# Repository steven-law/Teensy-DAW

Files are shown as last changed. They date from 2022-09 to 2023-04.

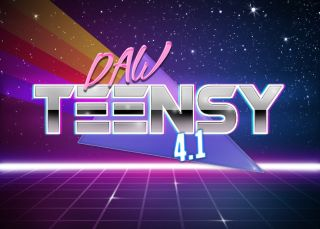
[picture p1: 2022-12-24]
sdcontent/StartUpPic.bmp

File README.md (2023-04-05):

#
Please join this Discord channel for best feature updates, informations and other chats.  
The most updated files are still here, tho.  
https://discord.gg/N78atDz9bC
please Note:
At the moment the latest updates are in the "Steven-Law" branch

Teensy-DAW
 clipbased Touch DAW for Teensy

.) 8 tracks  
.) 8 individual clips per track  
.) 16 steps per clip  
.) +4 different Sequencer Modes ("Step", "Grid", "Drop", "Rand")  
.) sequence external Midi gear (Midichannel 1 - 16) or (if "Midichannel" is above 16)  
.) 8+ internal plugins , several sampleplayers and synthesis  
.) each plugin can save 8 presets to sd card  
.) more plugins can be easily added. Tutorial inside  
.) send 16 midi cc´s per track when Midichannel is set to 1-16  
.) whole project or each page can be saved/loaded indiviually to sd card  
.) Songmode /Arrangement Mode  
.) navigation via touchscreen, buttons or encoders  
.) control 4 paramters in a row immediatly with the knobs or 4 pots from your controller/keyboard  
.) automatic pot assign for different pages  
.) connect a keyboard like the keyste37 (or any other KB with 4 Knobs) for best integration  
.) connect up to 5 usbmidi-synthesizer over a usb-hub/ or standard TRS Type A = Korg/Roland/..  
.) Record or play live via USB Keyboard  
.) Record external Audio to RAW files   
.) scales can be highlighted in sequencer view  
.) use a Launchpad mini (MK1) to launch Clips directly  
.) 

Implemented plugins:  
1) Chord-Plugin  
2) SdCard-WAV Drumplayer, very rudimentary for now   
3) 1OSC Voice  (with Tutorial)  
4) FlashMem Drumplayer  
5) SD melodic sampler  
6) SD *.raw melodic sampler  
7) drum synth  
8) 1OSC with moog ladder filter   

Songmode:  
.) the individual clips can be arranged in songmode  
.) songs can be up to 255 bars long  
.) set individual note offsets (transpose) per beat  
.) set individual Plugin Preset per beat  
.) set individual Volumes per beat  
.) loop function to loop desired bars  
.)   
  
Drumtrack:  
.) sequence one of the internal drum plugins   
.) send up to 12 individual Midi notes to ext gear like Drummachines  
.) sent notes can be easily applied  
.)   
  
Melodic Tracks 2-8:  
.) sequence one of the internal melodic plugins   
.) send Midinotes to ext gear like Monophonic Synthesizers  
.)   
  
Mixer:  
.) mix internal plugins / MIDI Velocity  
.) solo and mute function  
.) 3 fx slots with individual sends per track  
.)  
  
Audio Recorder:  
.) Record Line Level to RAW  
.) choose one of 128 RAW Files  
.) apply Gain to the signal  
.) Pre-Listen /Monitor your signal  
.) record by hitting Rec, press again to stop recoording  
.)

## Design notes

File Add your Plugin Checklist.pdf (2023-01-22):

# Add your Plugin Checklist

.) Think yourself of a cool Plugin

.) Implement the modules into the Teensy-Touch-DAW Audiochain.

.) Export the new AudioChain and replace it with the existing one

.) Add the 6 Gainstages to the Array of pointers

.) Place your control variables in variables.ino.

.) Add these 7 functions to your new plugin *.ino file

.) “void Plugin_3_Settings()”

.) “void Plugin3_Control()”

.) “void Plugin3_Page1_Dynamic()”

.) “void Plugin3_Page_Static(byte Pagenumber)”

.) “void Plugin3_Change()”

.) “void savePlugin3()”

.) “void loadPlugin3()”

.) Think yourself of a cool Plugin and what controls you want to have

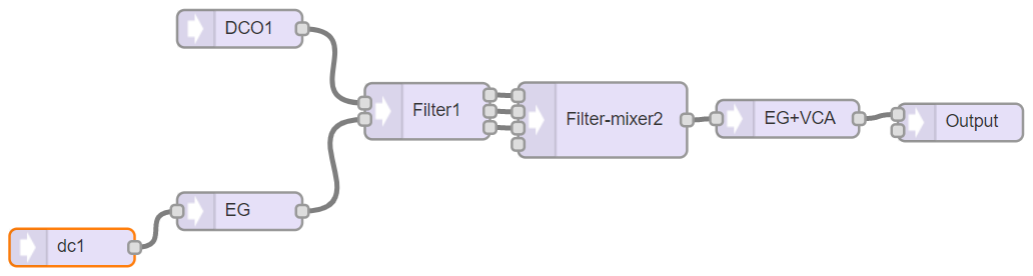
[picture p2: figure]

.) Implement the modules into the Teensy-Touch-DAW Audiochain.
Copy the existing AudioChain-Code into Newdigate´s AudioTool. Paste your Plugin inside. Don't forget the 2 Gain stages for MAX Volume and Volume/bar
as well as the 4 Gain modules for the FX´s

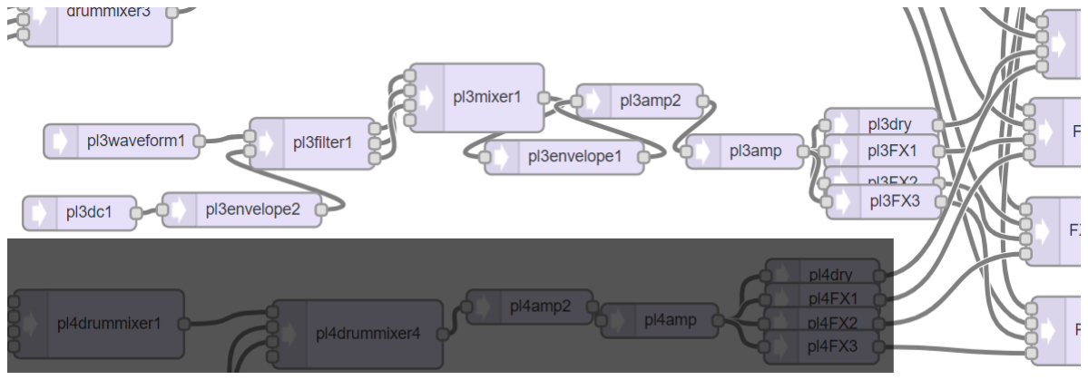
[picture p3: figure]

.) Export the new AudioChain and replace it with the existing one

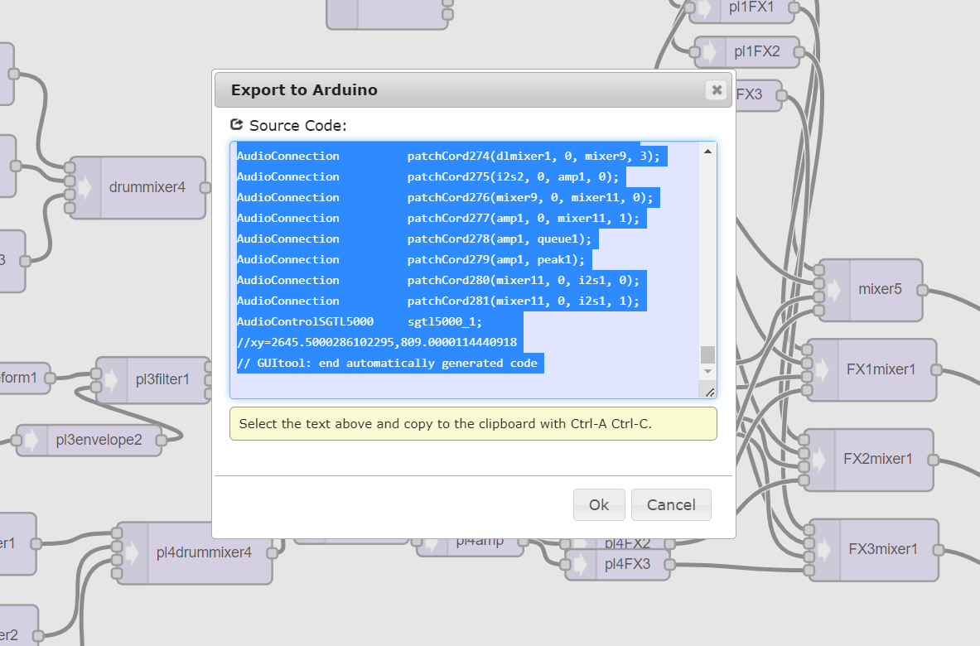
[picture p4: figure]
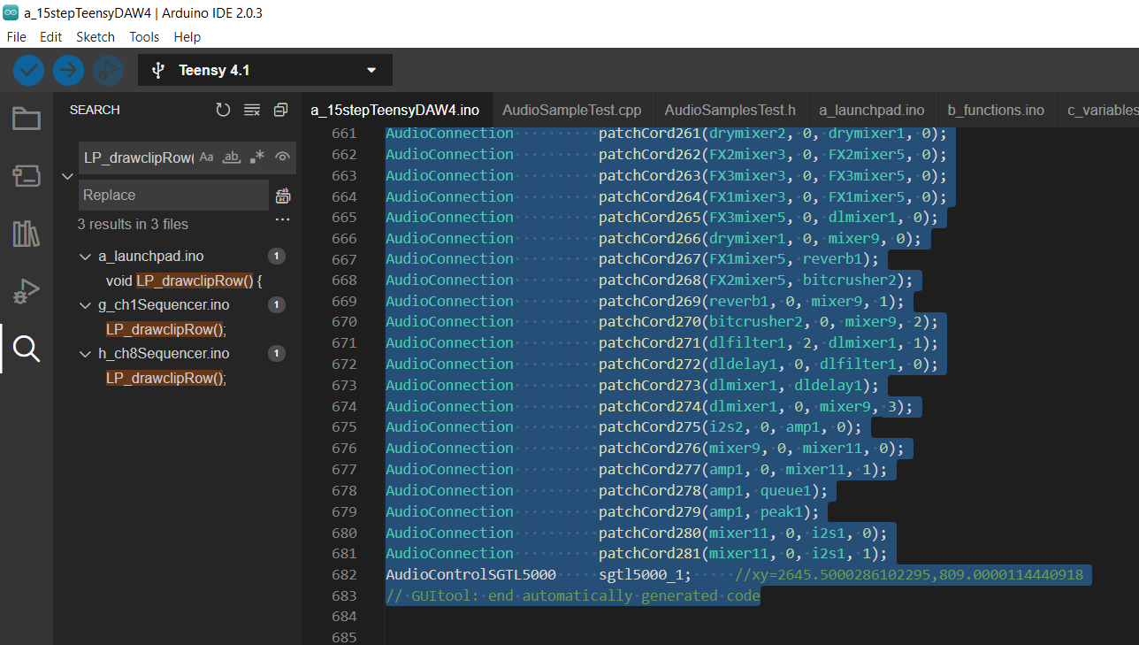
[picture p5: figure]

=>

.) *Add the 6 Gainstages to the Array of pointers
* If we have reached the max amount of Plugins, i´ve made a template for, we have to add new Gain stages. But there is most likely also other stuff to do

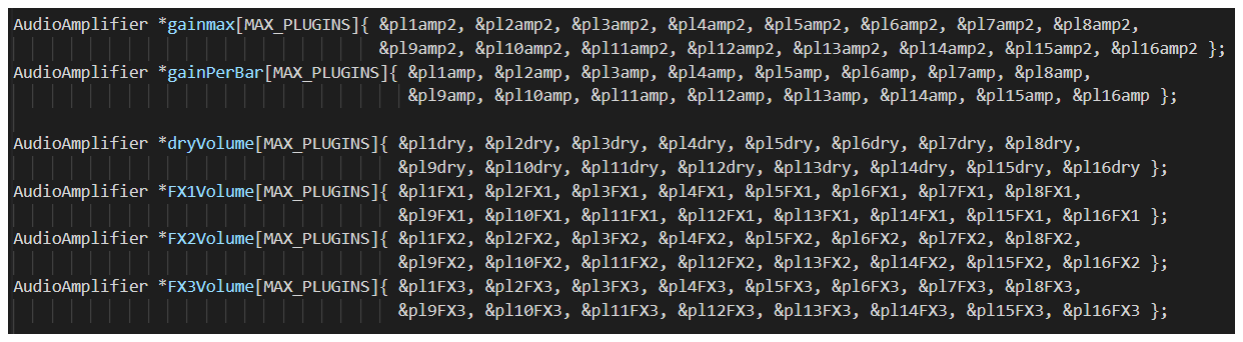
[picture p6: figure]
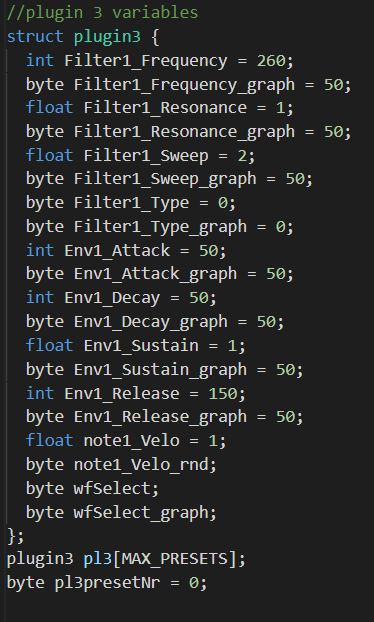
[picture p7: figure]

.) Place your control variables in variables.ino.
Use a “struct” for saving presets. For each control you need 2 variables:

byte/float/int “module_function”; // your desired range
byte | “module_function”_graph; // range: 0-127

Also set your Plugin name into the PluginName[] Array!!

.) Add these 7 functions to your new plugin *.ino file void Plugin_3_Settings()
void Plugin3_Control()
void Plugin3_Page1_Dynamic()
void Plugin3_Page_Static(byte Pagenumber) void Plugin3_Change()

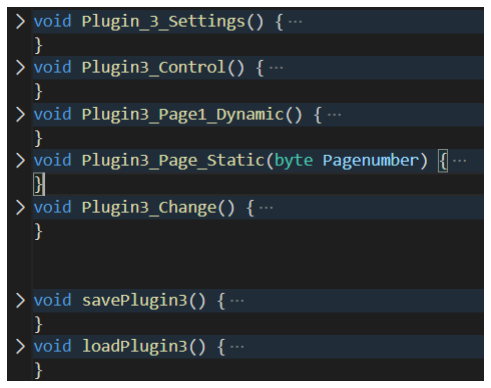
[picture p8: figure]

void savePlugin3()
void loadPlugin3()

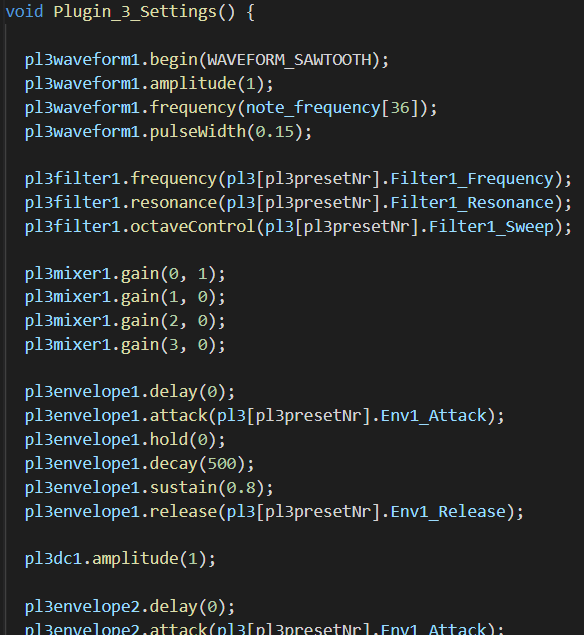
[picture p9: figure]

.) “void Plugin_3_Settings()”
This function is used to set all functions from the used Modules to a desired start value.
Give all functions a desired value. Some functions may not be used, but then they are set to the correct value.

Copy this function in “functions.ino to:
void setup {}

.) “void Plugin3_Control()”
This function is used to map the _graph value to the desired “function”-range.
For every function you want to control add your assignment here. Each switch-case stands for one of the four rows. This is the most code you have to write. In the end your “PluginX_Control” function will be about 100 lines long, if you use this method:

if (pl3[pl3presetNr].***_graph != Potentiometer[x]) {
pl3[pl3presetNr].***_graph = Potentiometer[x];
pl3[pl3presetNr].*** = map(pl3[pl3presetNr].***_graph, 0, 127, min, max); module.function(pl3[pl3presetNr].***);
drawPot(CTRL_COL_x, CTRL_ROW_x, pl3[pl3presetNr].***_graph, pl3[pl3presetNr].***, "***", trackColor[desired_track]);
}
where *** is the desired function.

Copy this function in “functions.ino to: void Plugin_View_Dynamic() {}

.) “void Plugin3_Page1_Dynamic()”
This function is used to assign the Encoder Movement to the desired _graph value. Here we add the Encoder value to the last stored “plX[desired_track].***_graph” value and give it to “Potentiometer[x]”. Do this for every control you have added above.

Potentiometer[x] = pl3[pl3presetNr].***_graph;
if (enc_moved[x]) {
Potentiometer[x] = constrain((pl3[pl3presetNr].***_graph + encoded[0]), 0, 127); }
where *** is the desired function.

Copy this function in “functions.ino to:
void Plugin_View_Dynamic() {}

.) “void Plugin3_Page_Static(byte Pagenumber)”
This function is used to show your controls once after you switch presets.
Copy the drawPot() functions from “PluginX_Control” into this function. Whenever you call your Plugins Page, these are the things that will show up. Add “clearworkspace()”, your “PluginX_Change()” and the rectangle for the Preset Number functions. This function is only called once.Don't put any interactive stuff inside.

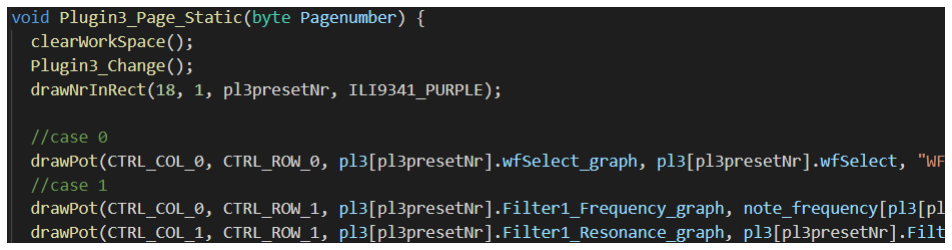
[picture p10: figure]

Copy this function in “functions.ino to: void Plugin_View_Static() {}

.) “void Plugin3_Change()”
This function is used for preset changes.
Copy the | module.function(pl3[pl3presetNr].***); | module´s functions into this page.

Copy this function in “functions.ino to:
void beatComponents {}
and your
void Plugin3_Page_Static(byte Pagenumber)

.) “void savePlugin3()”
This function is used to save your Presets.
Copy one of the existing save_Plugin() functions into your file and change the _graph variable to yours.

Copy this function in “songmode.ino to:
void savebutton {}
and your
void Plugin3_Page_Dynamic()

.) “void loadPlugin3()”
This function is used to load your Presets.
Copy one of the existing load_Plugin() functions into your file and change the _graph variable to yours.

Copy this function in “songmode.ino to:
void loadbutton {}
and your
void Plugin3_Page_Dynamic()

.) NoteOn/NoteOff´s
Add your NoteOn/NoteOff´s into the “void PluginPlay()” function.
From here your Plugin will be played via the sequencer, a MIDI Keyboard or the Launchpad.

Done!!!

Useful Lines:
selectFilterType(pluginchannel, mixerchannel) //if you want a selectable filtertype add your filtermixer inside
drawPot(xPos, yPos, fvalue, dvalue, dname, color); | //fvalue = ***_graph; dvalue = ***
drawNrInRect(xPos, yPos, dvalue, color); | // dvalue = ***
clearWorkSpace();

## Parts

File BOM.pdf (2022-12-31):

| | BOM
1 | 1 | Teensy 4.1 | https://www.pjrc.com/store/teensy41.html
2 | 1 | Teensy Audio Shield Rev D | https://www.pjrc.com/store/teensy3_audio.html
3 | 1 | TFT ILI9341 2.8" | https://www.amazon.de/gp/product/B07YTWRZGR/ref=ppx_yo_dt_b_asin_title_o00_s00?ie=UTF8&psc=1
4 | 4 | Encoder with switch | any will do
5 | 16 | 6x6mm tactile switch | https://www.mouser.at/ProductDetail/E-Switch/TL1105SPF160Q?qs=01kh3H%252BlXiincFtVDb4Rog%3D%3D
6 | 16 | 1RWHT caps | https://www.mouser.at/ProductDetail/612-1RWHT
7 | 4 | SJ1-3533NG stereo jack | https://www.mouser.at/ProductDetail/490-SJ1-3533NG
8 | 2 | 929870-01-14-RA flat header | https://www.mouser.at/ProductDetail/517-929870-01-14-RA
9 | 17 | 1N4148 Diodes | https://www.mouser.at/ProductDetail/onsemi-Fairchild/1N4148?qs=i4Fj9T%2FoRm8RMUhj5DeFQg%3D%3D
10 | 2 | 47R Resistor | any will do
11 | 1 | 100R Resistor | any will do

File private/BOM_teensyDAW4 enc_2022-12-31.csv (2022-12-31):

ID | Name | Designator | Footprint | Quantity | Manufacturer Part | Manufacturer | Supplier | Supplier Part | Price
1 | 1N4148 | D1,D2,D3,D4,D5,D6,D7,D8,D9,D10,D11,D12,D13,D14,D15,D16,D17 | DO-35_BD2.0-L4.2-P8.20-D0.5-RD | 17 | 1N4148 | STMicroelectronics | LCSC | C13769
2 | SJ1-3533NG | J1,J2,J3,J4 | JACK_3.5MM-SJ1-3533NG | 4 | SJ1-3533NG | null | LCSC | C9900019346
3 | 220R | R1,R2 | R_AXIAL-0.3 | 2
4 | 100R | R5 | R_AXIAL-0.6 | 1
5 | TC-1102-C-P-B | SW1,SW2,SW3,SW4,SW5,SW6,SW7,SW8,SW9,SW10,SW11,SW12,SW13,SW14,SW15,SW16 | KEY-TH_4P-L6.0-W6.0-P4.50-LS6.50 | 16 | TC-1102-C-P-B | XKB Connectivity(中国星坤) | LCSC | C2885143 | 0.005
6 | TEENSY_41_AUDIO_SHIELD_ONLY COPY | T1 | TEENSY_4_1_AUDIO_SHIELD_ONLY COPY | 1 | PJRC
7 | MYTFT_TOUCH_SPI_2.8IN-ILI9341 COPY | U1 | MYTFT_TOUCHSPI_2.8IN-ILI9341 | 1
8 | Teensy_4.1 | U2 | TEENSY4.1UNTEN | 1 | Teensy_4.1 | PJRC | www.pjrc.com | Teensy_4.1
9 | ENCODER_SW1-PEC12 | SW17,SW18,SW19,SW20 | PEC12_INCREMENTAL_ENCODER | 4

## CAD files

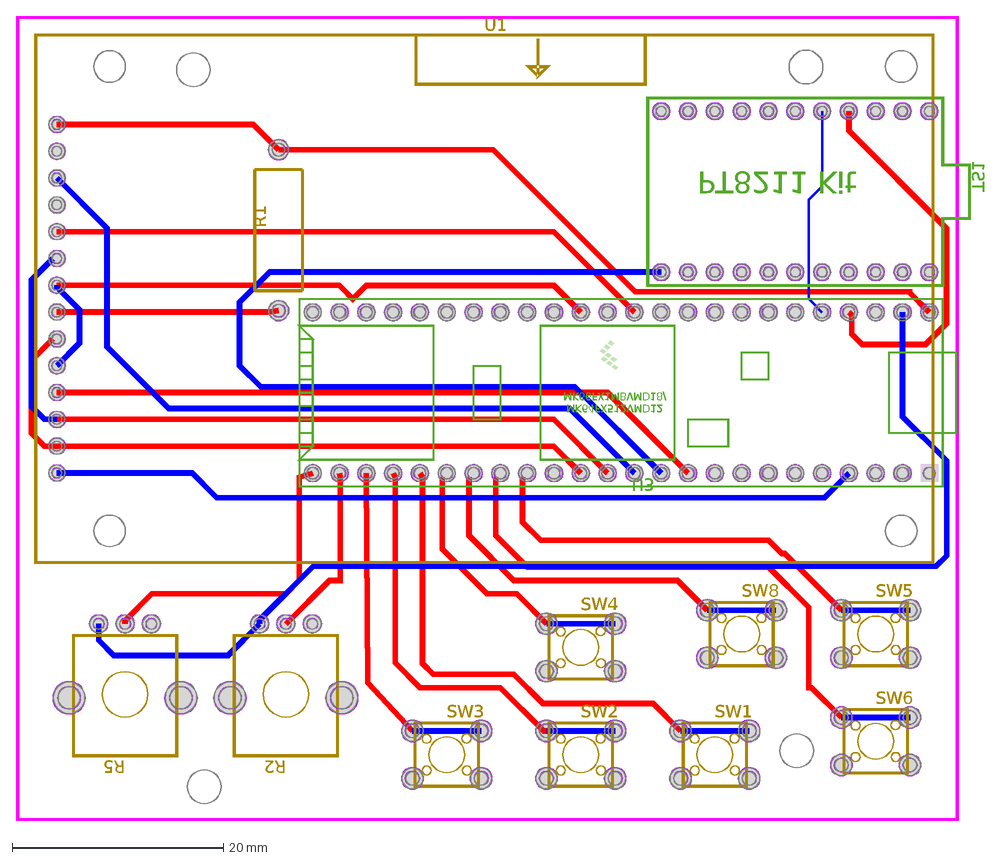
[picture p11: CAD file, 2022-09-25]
hardware/PCB_teensyDAW_2022-09-21.dxf
TS1
PT8211 Kit
U3
MK66FX1MBVMD18/
MK64FX512VMD12
SW1
SW2
SW3
SW4
SW5
SW6
SW8
R1
R5
U1
R2

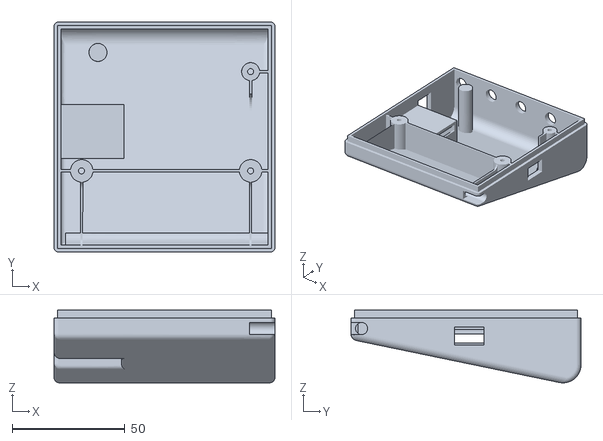
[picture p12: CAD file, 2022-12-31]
Housing/touchdaw41Enc.stl
98.0 x 102.0 x 32.3

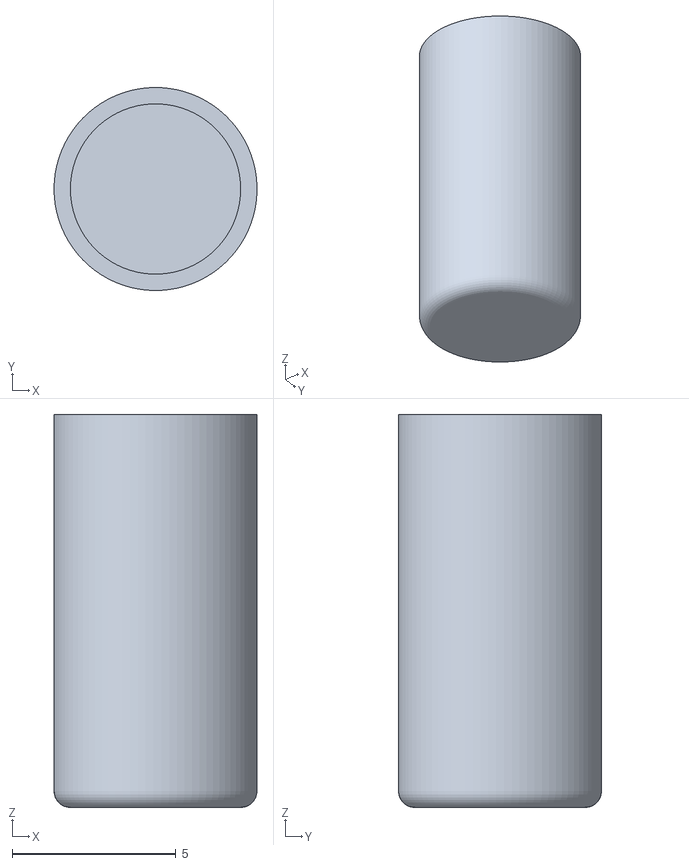
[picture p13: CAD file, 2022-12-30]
Housing/buttonextension12.stl
6.20 x 6.20 x 12.0

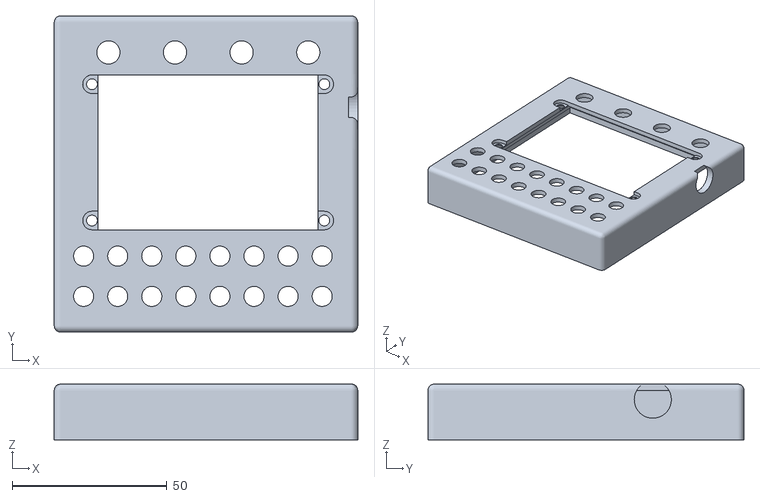
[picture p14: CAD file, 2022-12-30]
Housing/touchdaw41obenEnc.stl
98.0 x 102.0 x 18.0

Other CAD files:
hardware/PCB_teensyDAW_2022-09-21-2.dxf
hardware/PCB_teensyDAW_2022-09-21-2.dwg

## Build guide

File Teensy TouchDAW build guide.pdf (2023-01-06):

# Build Guide:

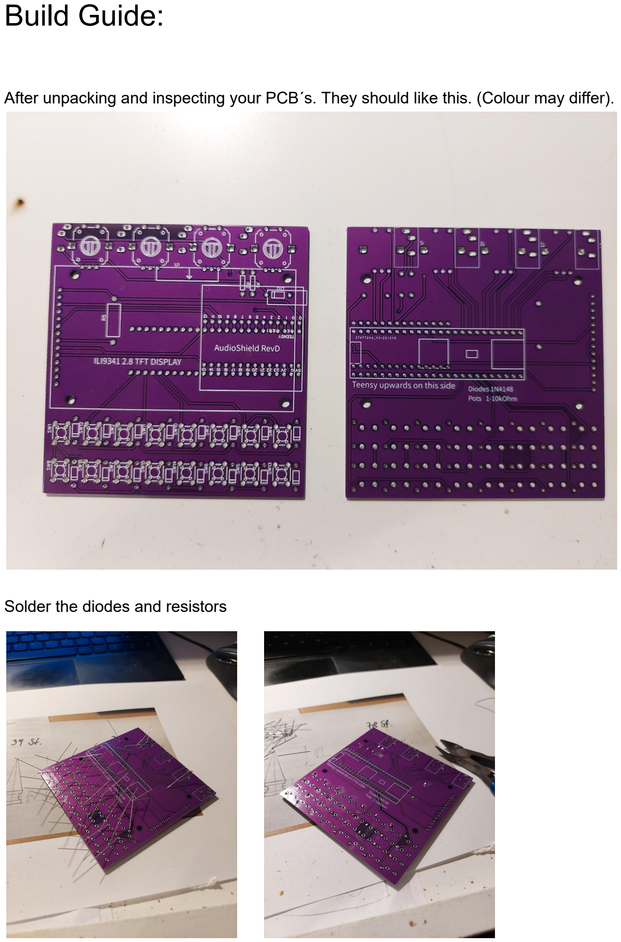
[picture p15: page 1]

After unpacking and inspecting your PCB´s. They should like this. (Colour may differ).

Solder the diodes and resistors

Solder the Buttons

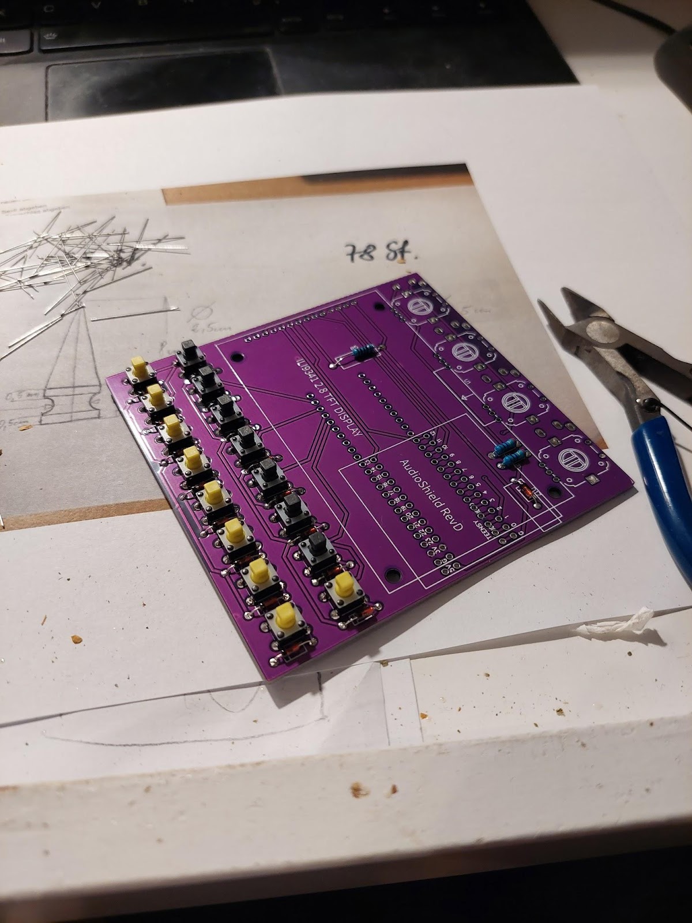
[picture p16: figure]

Solder the headers
- long headers on the backside
- short headers on the top side
- header for display on the top side

Solder the Encoders

Solder Teensy 4.1 headers
- pay attention to the orientation

Sodler Audio shield Headers
- pay attention to the pin length

tbc

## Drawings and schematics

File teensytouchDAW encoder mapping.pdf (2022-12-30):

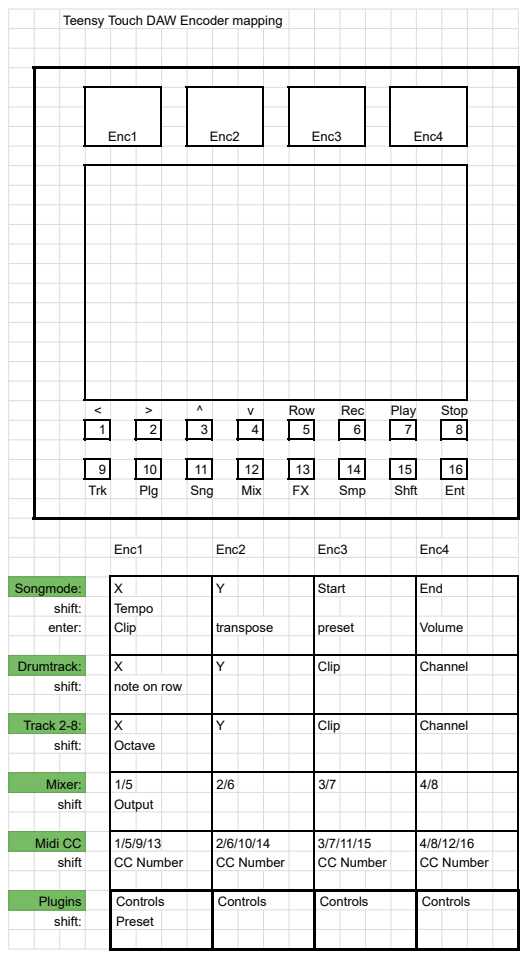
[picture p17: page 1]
Enc1; Enc2; Enc3; Enc4; Row; Rec; Stop; Trk; Plg; Sng; Mix; Smp; Shft; Ent; Songmode:; Start; End; shift:; Tempo; enter:; transpose; preset; Volume; Drumtrack:; Channel; note on row; Track 2-8:; Octave; Mixer:; shift; Output; Midi CC; CC Number; Plugins; Controls; Preset; Play

Teensy Touch DAW Encoder mapping

Clip

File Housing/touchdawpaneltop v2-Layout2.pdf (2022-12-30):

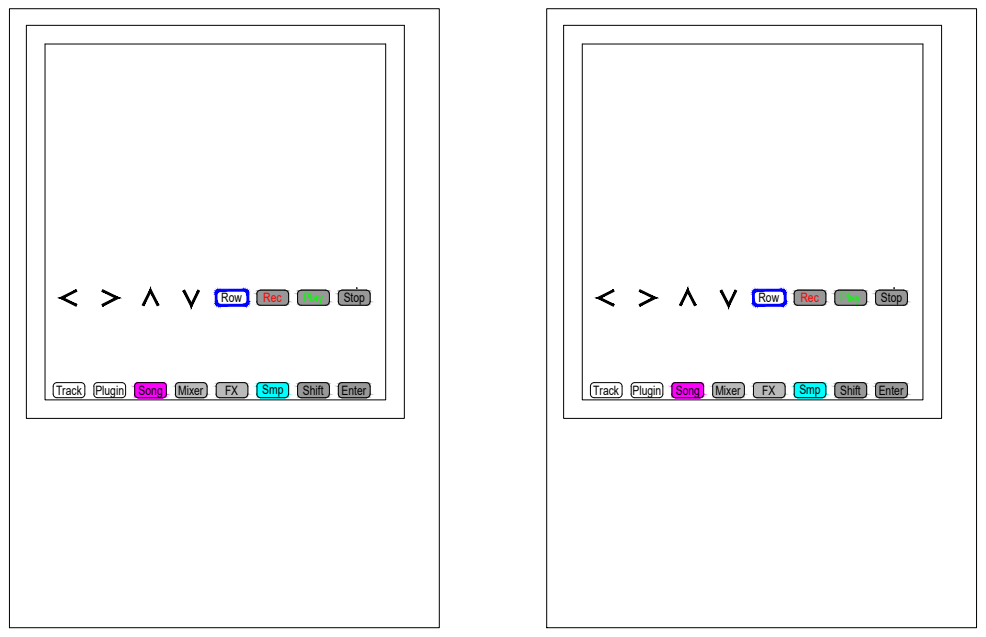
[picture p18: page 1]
Track; Plugin; Song; Mixer; Shift; Enter Rec; Play; Stop FX; Smp Row Track; Smp Row

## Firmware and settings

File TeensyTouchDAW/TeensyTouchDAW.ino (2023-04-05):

bool debugTime = false;
extern unsigned long _heap_start;
extern unsigned long _heap_end;
extern char *__brkval;
/*Contributing Manual:

Many Thanks to Tristan Rowley, without his immense efforts and time to explain things to me, 
this project would have never reached this amount of functions and still have a more or less readable code. 
For more Informations on him, please take a look at www.github.com/doctea and www.doctea.co.uk!!  
Very Interesting stuff to find and try out!!!

Hello. Here i will show you how to implement new stuff easily.

There are some things left to be made at this point, but feel free to add your features.

toDo´s:
    • add polyphony
    • if in the stepsequencer of a track, i would like to hear the selected clip. when in songmode, only play the arrangment 



1. 15stepTeensyDAW3.ino :

This is the main sketch. It is easier to look at it in chapters: 
Including all the librarys and the .h file
calibration and customizing
initiate the modules
Place for the PJRC GUItool for the internal plugins (audio Connections)

void loop(), run, the sequencer, reading the inputs. Applying all the controls from the 	startscreen when touched(trackselection, transportcontrol, arrengmenttype).
With each touch on one of the controls we switch all other functions to „false/LOW“ 	so the touches are not misinterpreted. After setting the state the code will open up 	the desired „window“.

Touch XY input is mapped to a grid of x=20, y=15 frames! 		
Each frame has a Frameheight and -width of 16 pixels.     		

void savebutton() if we hit the save button, do all the savings. Right now it saves the clip-array into one big junk of ascii´s, that is read when loading.
void loadbutton() Loading the clips array from the sd card.
void startUpScreen() here are all the graphical elements from the startupscreen 
void showCoordinates() shows the actual touch-coordinates

Head over to Pl31OSC.ino to see how to implement new plugins
*/


#include <Audio.h>
#include <Wire.h>
#include <SerialFlash.h>
#include <ILI9341_t3.h>
#include <font_Arial.h>  // from ILI9341_t3
//#include <ILI9341_t3n.h>
//#include "ili9341_t3n_font_Arial.h"
#include <XPT2046_Touchscreen.h>
#include <SPI.h>
#include <SD.h>
#include <TeensyVariablePlayback.h>
#include "flashloader.h"
#include "b_variables.h"
#include "b_pluginVariables.h"
#include "b_plugin_Audiopath.h"
#include "b_plugin_Audiopointers.h"

#include "Adafruit_Keypad.h"
#include <ResponsiveAnalogRead.h>
#include <USBHost_t36.h>
#include <Encoder.h>
#include <MIDI.h>
#include "v_smfwriter.h"

// WAV files converted to code by wav2sketch
//#include "AudioSampleSnare.h"         // http://www.freesound.org/people/KEVOY/sounds/82583/
//#include "AudioSampleTomtom.h"        // http://www.freesound.org/people/zgump/sounds/86334/
//#include "AudioSampleHihat.h"         // http://www.freesound.org/people/mhc/sounds/102790/
//#include "AudioSampleKick.h"          // http://www.freesound.org/people/DWSD/sounds/171104/
//#include "AudioSampleCashregister.h"  // http://www.freesound.org/people/kiddpark/sounds/201159/
//#include "AudioSampleP2.h"
#include "AudioSamplesTest.h"



//Teensy 4.1 PINOUT
//Pinout for screen
#define TIRQ_PIN 15  //alternate Pins: any digital pin
#define CS_PIN 14    //alternate Pins: any digital pin
#define TFT_DC 9     //alternate Pins 9, 10, 20, 21
#define TFT_CS 10    //alternate Pins 9, 15, 20, 21
#define TFT_RST 255  // 255 = unused, connect to 3.3V
#define TFT_MOSI 11  //shareable
#define TFT_SCLK 13  //shareable
#define TFT_MISO 12  //shareable

//button Pins
const byte ROWS = 4;  //four rows
const byte COLS = 4;  //four columns
//define the cymbols on the buttons of the keypads
const char keys[ROWS][COLS] = {
  { '0', '1', '2', '3' },
  { '4', '5', '6', '7' },
  { '8', '9', 'A', 'B' },
  { 'C', 'D', 'E', 'F' }
};
const byte rowPins[ROWS] = { 37, 36, 35, 34 };  //connect to the row pinouts of the keypad
const byte colPins[COLS] = { 41, 38, 39, 40 };  //connect to the column pinouts of the keypad

Adafruit_Keypad kpd = Adafruit_Keypad(makeKeymap(keys), rowPins, colPins, ROWS, COLS);
//Encoder Pins
Encoder Enc1(31, 32);
Encoder Enc2(27, 28);
Encoder Enc3(24, 25);
Encoder Enc4(2, 3);



//calibrate your Screen
// This is calibration data for the raw touch data to the screen coordinates
#define TS_MINX 440
#define TS_MINY 300
#define TS_MAXX 3850
#define TS_MAXY 3800

//touchscreen response; to be changed
const long interval = 200;

//pinout for SD CARD
const int chipSelect = BUILTIN_SDCARD;

//initial drumnotes
byte drumnote[12]{ 36, 37, 38, 39, 40, 41, 42, 43, 44, 45, 46, 47 };

//noteOn velocity for all tracks
#define VELOCITY 96



//individual trackcolors
int trackColor[9]{ 6150246, 8256638, 1095334, 12643941, 2583100, 9365295, 12943157, 5678954, ILI9341_WHITE };
//end of calibration and custumizing



//initiate the modules

File myFile;                                                                         //initiate SDCard Reader
ILI9341_t3 tft = ILI9341_t3(TFT_CS, TFT_DC, TFT_RST, TFT_MOSI, TFT_SCLK, TFT_MISO);  //initiate TFT-Srceen
//ILI9341_t3n tft = ILI9341_t3n(TFT_CS, TFT_DC, TFT_RST, TFT_MOSI, TFT_SCLK, TFT_MISO);  //initiate TFT-Srceen
//DMAMEM uint16_t fb1[320 * 240];


XPT2046_Touchscreen ts(CS_PIN);  //initiate Touchscreen
USBHost myusb;
USBHub hub1(myusb);
USBHub hub2(myusb);
USBHub hub3(myusb);
USBHub hub4(myusb);
MIDIDevice midi01(myusb);
MIDIDevice midi02(myusb);
MIDIDevice midi03(myusb);
MIDIDevice midi04(myusb);
MIDIDevice midi05(myusb);
MIDIDevice midi06(myusb);
MIDIDevice midi07(myusb);
MIDIDevice midi08(myusb);
MIDIDevice midi09(myusb);
MIDIDevice midi10(myusb);

MIDI_CREATE_INSTANCE(HardwareSerial, Serial1, MIDI);
#define MAX_USB_DEVICES 10
#define MIDI_VENDORID_LAUNCHPAD 4661
#define MIDI_PRODUCTID_LAUNCHPAD 54

MIDIDevice *launchpad = nullptr;
MIDIDevice *usb_midi_devices[MAX_USB_DEVICES] = { &midi01, &midi02, &midi03, &midi04, &midi05, &midi06, &midi07, &midi08, &midi09, &midi10 };
//please use this Audio GUI from Newdigate
//https://newdigate.github.io/teensy-eurorack-audio-gui/
elapsedMillis msecs;
elapsedMicros msecsclock;


class Clock {
public:
  uint32_t _next_clock = 0;
  uint32_t _clock = 160;
  uint32_t MIDItick = -1;
  uint32_t step_tick = -1;
  uint32_t bar_tick = -1;
  bool seq_run = false;
  bool seq_rec = false;
  bool playing = false;
  byte master_tempo = 120;
  int syncPin = -1;
  uint32_t previousMillis_clock = 0;

  //setup function, so we can put in an analog sync Output (Optional)
  void setup(int new_syncPin) {
    syncPin = new_syncPin;
    if (syncPin >= 0) {
      digitalWrite(syncPin, LOW);  //
      pinMode(syncPin, OUTPUT);
    }
  }

  bool is_playing() {
    return playing;
  }
  void set_playing(bool p = false) {  //if we want to start the clock use, "clock.is_playing(true);"
    this->playing = p;
  }
  void set_tempo(int tempo) {  //set the tempo with "clock.setTempo(tempo);"
    master_tempo = tempo;
    // midi clock messages should be sent 24 times
    // for every quarter note
    _clock = 60000000L / tempo / 24;
  }
  int get_tempo() {
    return master_tempo;
  }
  void send_MIDIclock() {
    //spit out a MIDItick
    usbMIDI.sendRealTime(usbMIDI.Clock);  //send a midiclock to usb host
    MIDI.sendRealTime(0xF8);              //send a midiclock to serial midi
  }
  void send_sync_clock() {

    //spit out a MIDItick
    if (syncPin >= 0) {
      digitalWrite(syncPin, HIGH);
      uint32_t currentMillis = millis();
      if (currentMillis - previousMillis_clock >= 10) {
        previousMillis_clock = currentMillis;
        digitalWrite(syncPin, LOW);
      }
    }
  }
  bool process_MIDItick() {

    if (playing) {
      //if the clock is running
      if (msecsclock >= _clock) {  //compare clockvalues
        MIDItick++;                //spit out a MIDItick
        send_MIDIclock();
        msecsclock = 0;

        return true;
      }
    }
    return false;
  }
  uint32_t get_MIDItick() {  //returns the actual MIDItick count
    return MIDItick;
  }



  uint32_t get_step_tick() {  //returns the actual STEPtick count
    return MIDItick % 6;
  }
  bool is_tick_on_step() {
    return MIDItick % 6 == 0;
  }


  uint32_t get_bar_tick() {  //returns the actual BARtick count
    return MIDItick % 96;
  }
  bool is_tick_on_bar() {
    return MIDItick % 96 == 0;
  }
};

Clock master_clock;







void setup() {
  Serial.begin(15200);  // set MIDI baud
  //initialize the TFT- and Touchscreen
  tft.begin();
  tft.setRotation(3);
  ts.begin();
  ts.setRotation(1);
  //tft.setFrameBuffer(fb1);
  //tft.useFrameBuffer(true);
  while (!Serial && (millis() <= 1000))
    ;
  tft.fillScreen(ILI9341_BLACK);  //Xmin, Ymin, Xlength, Ylength, color
  tft.setTextColor(ILI9341_WHITE);
  tft.setFont(Arial_8);
  tft.setCursor(0, 3);
  Serial.println("Initializing Touchscreen...");
  tft.println("Initializing Touchscreen...");
  //tft.updateScreen();
  delay(100);

  //initialize SD Card
  Serial.print("Initializing SD card...");
  tft.println("Initializing SD card...");
  //tft.updateScreen();
  delay(100);
  if (!SD.begin(chipSelect)) {
    Serial.println("initialization failed!");
    tft.println("initialization failed!");
    //tft.updateScreen();
    return;
  }
  Serial.println("initialization done.");
  tft.println("initialization done.");
  //tft.updateScreen();
  delay(100);



  AudioMemory(AUDIO_MEMORYS);
  Serial.print("Initializing AudioMemory = ");
  Serial.println(AUDIO_MEMORYS);
  tft.print("Initializing AudioMemory = ");
  tft.println(AUDIO_MEMORYS);

  //tft.updateScreen();
  delay(100);




  // start sequencer and set callbacks and load big arrays

  Serial.println("Initializing Sequencer");
  tft.println("Initializing Sequencer");
  // Allocate channel1Clip array during runtime

  channel1Clip = new bool **[NUM_CLIPS];
  for (int i = 0; i < NUM_CLIPS; i++) {
    channel1Clip[i] = new bool *[num_voice];
    for (int j = 0; j < num_voice; j++) {
      channel1Clip[i][j] = new bool[STEP_QUANT];
    }
  }
  // fill the array
  for (int i = 0; i < NUM_CLIPS; i++) {
    for (int j = 0; j < num_voice; j++) {
      for (int k = 0; k < STEP_QUANT; k++) {
        channel1Clip[i][j][k] = 0;
      }
    }
  }

  //ratcheting array
  ratchet = new bool **[NUM_CLIPS];
  for (int i = 0; i < NUM_CLIPS; i++) {
    ratchet[i] = new bool *[num_voice];
    for (int j = 0; j < num_voice; j++) {
      ratchet[i][j] = new bool[STEP_QUANT];
    }
  }
  // fill the array
  for (int i = 0; i < NUM_CLIPS; i++) {
    for (int j = 0; j < num_voice; j++) {
      for (int k = 0; k < STEP_QUANT; k++) {
        ratchet[i][j][k] = 0;
      }
    }
  }
  // Allocate dsend_noteOff array during runtime
  dsend_noteOff = new bool[num_voice];
  //tft.updateScreen();

  //allocate tracks2-8 "array"
  ctrack = calloc(NUM_TRACKS, sizeof(track_t));
  //allocate tracks
  track = new tracks[NUM_TRACKS];
  //ctrack = new track_t[NUM_TRACKS];
  //allocate plugins
  plugin = new plugin_t[MAX_PLUGINS];
  effect = new effect_t[MAX_EFFECTS];
  //allocate NFX1
  NFX1 = new Grids[MAX_PRESETS];
  //allocate NFX2
  NFX2 = new Drops[MAX_PRESETS];
  //allocate NFX3
  NFX3 = new rands[MAX_PRESETS];
  //allocate NFX4
  NFX4 = new PolyR[MAX_PRESETS];
  //allocate NFX5
  NFX5 = new Ratch[MAX_PRESETS];
  //allocate LaunchPad arrays
  LP_grid_notes = new byte[64];
  for (int r = 0; r < 8; r++) {
    for (int c = 0; c < 8; c++) {
      LP_grid_notes[r + (c * 8)] = r + (c * 16);
    }
  }

  LP_step_notes = new byte[16];
  for (int r = 0; r < 8; r++) {
    for (int c = 0; c < 2; c++) {
      LP_step_notes[r + (c * 8)] = (r + 16) + (c * 16);
    }
  }
  note_frequency = new float[128];
  for (int r = 0; r < 128; r++) {
    note_frequency[r] = pow(2.0, ((double)(r - SAMPLE_ROOT) / 12.0));
  }
  delay(100);


  //start usbhost
  Serial.println("Initializing USB Host");
  tft.println("Initializing USB Host");
  myusb.begin();
  midi01.setHandleNoteOn(myNoteOn);
  midi01.setHandleNoteOff(myNoteOff);
  midi01.setHandleControlChange(myControlChange);
  midi02.setHandleNoteOn(myNoteOn);
  midi02.setHandleNoteOff(myNoteOff);
  midi02.setHandleControlChange(myControlChange);
  midi03.setHandleNoteOn(myNoteOn);
  midi03.setHandleNoteOff(myNoteOff);
  midi03.setHandleControlChange(myControlChange);
  midi04.setHandleNoteOn(myNoteOn);
  midi04.setHandleNoteOff(myNoteOff);
  midi04.setHandleControlChange(myControlChange);
  midi05.setHandleNoteOn(myNoteOn);
  midi05.setHandleNoteOff(myNoteOff);
  midi05.setHandleControlChange(myControlChange);
  midi06.setHandleNoteOn(myNoteOn);
  midi06.setHandleNoteOff(myNoteOff);
  midi06.setHandleControlChange(myControlChange);

  usbMIDI.setHandleNoteOn(myNoteOn);
  usbMIDI.setHandleNoteOff(myNoteOff);
  usbMIDI.setHandleControlChange(myControlChange);
  //usbMIDI.setHandleClock(myClock);
  //usbMIDI.setHandleStart(myStart);
  //usbMIDI.setHandleStop(myStop);
  MIDI.begin();
  pinMode(22, OUTPUT);
  //tft.updateScreen();
  delay(100);

  /// set the default channel of each track
  track[0].MIDIchannel = 9;
  track[1].MIDIchannel = 2;
  track[2].MIDIchannel = 3;
  track[3].MIDIchannel = 4;
  track[4].MIDIchannel = 5;
  track[5].MIDIchannel = 6;
  track[6].MIDIchannel = 7;
  track[7].MIDIchannel = 8;
  //!!!!!!!!!!!!!!!!!!!!!!!!!!!!!!!!!!!!!!!!!!!!!!!!!!!!!!!!!!!!!!!!!!!!!!!!!
  //load the pluginsettings

  Plugin_1_Settings();
  Plugin_2_Settings();
  Plugin_3_Settings();
  Plugin_4_Settings();
  Plugin_5_Settings();
  Plugin_6_Settings();
  //Plugin7_Settings();
  Plugin_8_Settings();
  Plugin_9_Settings();
  Plugin_10_Settings();
  Plugin_11_Settings();
  Plugin_12_Settings();
  Plugin_13_Settings();
  Plugin_14_Settings();
  Plugin_15_Settings();
  Plugin_16_Settings();
  Mixer_Settings();
  FX1reverb_settings();
  FX2Bitcrush_settings();
  FX3Delay_settings();

  clearArrangment();
  Serial.println("Initializing Track- and Pluginsettings");
  tft.println("Initializing Track- and Pluginsettings");
  for (int pluginn = 0; pluginn < MAX_PLUGINS; pluginn++) {
    dryVolume[pluginn]->gain(1);
    FX1Volume[pluginn]->gain(0);
    FX2Volume[pluginn]->gain(0);
    FX3Volume[pluginn]->gain(0);
  }


  //tft.updateScreen();
  delay(100);




  Serial.println("Initializing Buttons");
  tft.println("Initializing Buttons");
  kpd.begin();
  long positionEnc[4] = { -999, -999, -999, -999 };
  pinMode(30, INPUT_PULLUP);
  pinMode(29, INPUT_PULLUP);
  pinMode(26, INPUT_PULLUP);
  pinMode(4, INPUT_PULLUP);
  //tft.updateScreen();
  delay(100);


  //initiate variablePlayback
  playSdPitch1.enableInterpolation(true);
  playSdPitch2.enableInterpolation(true);
  Serial.println("Initializing VariablePlayback");
  tft.println("Initializing VariablePlayback");

  //tft.updateScreen();
  delay(100);
  Serial.println("Complete...");
  tft.println("Complete...");
  //tft.updateScreen();
  delay(400);
  //load the startupScreen

  for (int pixelX = 0; pixelX < 16; pixelX++) {
    for (int pixelY = 0; pixelY < 16; pixelY++) {
      tftRAM[pixelX][pixelY] = tft.readPixel(pixelX, pixelY);
    }
  }
  bmpDraw("StartUpPic.bmp", 0, 0);
  delay(400);  //just to look how beautiful this image is
  tft.fillScreen(ILI9341_DARKGREY);
  startUpScreen();
  delay(500);

  drumStepSequencer_Static();
  //tft.updateScreen();
}



long oldEnc[4] = { -999, -999, -999, -999 };



void loop() {

  //Serial.println("==== start of loop ====");
  usbMIDI.read();
  myusb.Task();
  midi01.read();
  midi02.read();
  midi03.read();
  midi04.read();
  midi05.read();
  midi06.read();
  midi07.read();
  midi08.read();
  midi09.read();
  midi10.read();
  detect_and_assign_midi_devices();
  kpd.tick();
  process_clock();


  readMainButtons();
  readEncoders();
  Plugin_View_Dynamic();
  DrumPluginPlay();
  PluginNoteOn();
  PluginNoteOff();

  otherCtrlButtons = (!button[8] && !button[9] && !button[10] && !button[11] && !button[12]);

  //placeholder for debugging
  if (msecs % 500 == 0) {
  }

  if (gridTouchY == 1) trackTouchY = 0;
  if (gridTouchY == 3) trackTouchY = 1;
  if (gridTouchY == 4) trackTouchY = 2;
  if (gridTouchY == 6) trackTouchY = 3;
  if (gridTouchY == 7) trackTouchY = 4;
  if (gridTouchY == 9) trackTouchY = 5;
  if (gridTouchY == 10) trackTouchY = 6;
  if (gridTouchY == 12) trackTouchY = 7;

  if (ts.touched()) {
    readTouchinput();
  }
  if (ts.touched() || button[15]) {

    if (gridTouchY == 0) {  //Top Line Edits: Tempo, Play, Stop, Record, Scales, Arrangment select

      ///////////////////////////////////////////////////////////////////////////////////////////////////////////////////////
      //Play button
      if (gridTouchX == POSITION_PLAY_BUTTON || gridTouchX == POSITION_PLAY_BUTTON + 1) {
        startSeq();
      }

      ///////////////////////////////////////////////////////////////////////////////////////////////////////////////////////
      //Stop button
      if (gridTouchX == POSITION_STOP_BUTTON) {
        stopSeq();
      }

      ///////////////////////////////////////////////////////////////////////////////////////////////////////////////////////
      //arrangmentSelect button ; not used right now
      if (gridTouchX == POSITION_ARR_BUTTON || gridTouchX == POSITION_ARR_BUTTON + 1) {
        arrangmentSelect = map(Potentiometer[3], 0, 127, 0, 7);
        tft.fillRect(STEP_FRAME_W * POSITION_ARR_BUTTON + 2, 1, STEP_FRAME_W * 2 - 3, STEP_FRAME_H - 2, ILI9341_DARKGREY);  //Xmin, Ymin, Xlength, Ylength, color
        tft.setCursor(STEP_FRAME_W * POSITION_ARR_BUTTON + 3, 4);
        tft.setFont(Arial_8);
        tft.setTextColor(ILI9341_WHITE);
        tft.setTextSize(1);
        tft.print("Arr:");
        tft.print(arrangmentSelect + 1);
      }
      ///////////////////////////////////////////////////////////////////////////////////////////////////////////////////////
      //TempoSelect button
      if (gridTouchX == POSITION_BPM_BUTTON || gridTouchX == POSITION_BPM_BUTTON + 1) {
        if (abs(map(Potentiometer[0], 0, 127, 55, 200) - seq_tempo) < 10) {
          seq_tempo = map(Potentiometer[0], 0, 127, 55, 200);
          master_clock.set_tempo(seq_tempo);
          show_tempo();
        }
      }
      ///////////////////////////////////////////////////////////////////////////////////////////////////////////////////////
      //Scale Select
      if (gridTouchX == POSITION_SCALE_BUTTON || gridTouchX == POSITION_SCALE_BUTTON + 1) {
        selectPage = SCALESELECT;
        gridScaleSelector();
        scaleSelector();
        for (int i = 0; i < MAX_SCALES; i++) {
          tft.setCursor(STEP_FRAME_W * 2, STEP_FRAME_H * i + STEP_FRAME_H);
          tft.setFont(Arial_8);
          tft.setTextColor(ILI9341_WHITE);
          tft.setTextSize(1);
          tft.print(scaleNames[i]);
        }
      }
    }

    if (gridTouchX == 0) {  //Songmode- and Trackselection
      ////////////////////////////////////////////////////////////////////////////////////////////////////////////////////////////////////////////////////////
      //  select Songarranger
      if (gridTouchY == 0) {
        selectPage = 10;
        gridSongMode(songpageNumber);
      }
      /////////////////////////////////////////////////////////////////////////////////////////////////////////////////////////////////////////////////////////

      //////////////////////////////////////////////////////////////////////////////////////////////////////////////////////////////////////////////////////////////
      // assign trackcolours
      for (int tracks = 0; tracks < 4; tracks++) {
        tft.setFont(Arial_9);
        tft.setTextColor(ILI9341_BLACK);
        if (trackTouchY == tracks) {

          if (enc_moved[0]) {
            trackColor[tracks] = constrain((trackColor[tracks] + (encoded[0])), 0, 16777215);
            if (tracks == 0) {
              //Drumtrack button
              tft.fillRect(1, STEP_FRAME_H, 15, TRACK_FRAME_H, trackColor[0]);  //Xmin, Ymin, Xlength, Ylength, color
              tft.setCursor(4, TRACK_FRAME_H);
              tft.print("D");
            } else {
              //other tracks buttons

              tft.fillRect(1, TRACK_FRAME_H * (tracks + 1) - 8, 15, TRACK_FRAME_H, trackColor[tracks]);  //Xmin, Ymin, Xlength, Ylength, color
              tft.setCursor(4, TRACK_FRAME_H * (tracks + 1));
              tft.print(tracks + 1);
            }
          }
        }
        if (trackTouchY == tracks + 4) {

          if (enc_moved[0]) {
            trackColor[tracks + 4] = constrain((trackColor[tracks + 4] + (encoded[0])), 0, 16777215);

            //other tracks buttons

            tft.fillRect(1, TRACK_FRAME_H * ((tracks + 1) + 4) - 8, 15, TRACK_FRAME_H, trackColor[tracks + 4]);  //Xmin, Ymin, Xlength, Ylength, color
            tft.setCursor(4, TRACK_FRAME_H * ((tracks + 1) + 4));
            tft.print(tracks + 5);
          }
        }
      }
      /////////////////////////////////////////////////////////////////////////////////////////////////////////////////////////////////////////////////////////
      //  select Mixer
      if (gridTouchY == 13) {
        selectPage = MIXER_PAGE_1;
        mixerPage1_Static(0);
      }
    }
    //tft.updateScreen();
  }
  // tft.updateScreenAsync();
  // tft.waitUpdateAsyncComplete();
}
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

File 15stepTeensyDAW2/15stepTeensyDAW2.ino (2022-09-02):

#include <ILI9341_t3.h>
#include <font_Arial.h> // from ILI9341_t3
#include <XPT2046_Touchscreen.h>
#include <SPI.h>
#include "FifteenStep.h"

#define SEQUENCER_MEMORY 32768
FifteenStep seq = FifteenStep(SEQUENCER_MEMORY);

// set initial state for dynamic values
int tempo = 120;
int steps = 16;
int polyphony = 64;
// save button state
int button_last = 0;


#define CS_PIN  8
#define TFT_DC  9
#define TFT_CS 10
// MOSI=11, MISO=12, SCK=13

XPT2046_Touchscreen ts(CS_PIN);
#define TIRQ_PIN  2

ILI9341_t3 tft = ILI9341_t3(TFT_CS, TFT_DC);

unsigned long previousMillis = 0;
const long interval = 120;
byte barClock = 0;


// This is calibration data for the raw touch data to the screen coordinates
#define TS_MINX 180
#define TS_MINY 260
#define TS_MAXX 3730
#define TS_MAXY 3800

#define ch1COLOR 0
#define ch2COLOR 1
#define ch3COLOR 2
#define ch4COLOR 3
#define ch5COLOR 4
#define ch6COLOR 5
#define ch7COLOR 6
#define ch8COLOR 7
#define STEP_QUANT 16
#define STEP_FRAME_W 16
#define STEP_FRAME_H 16
#define TRACK_FRAME_H 24
#define SEQ_GRID_LEFT 2
#define SEQ_GRID_RIGHT 17
#define SEQ_GRID_TOP 1
#define SEQ_GRID_BOTTOM 12
#define GRID_LENGTH_HOR 256
#define GRID_LENGTH_VERT 192
#define POSITION_SCALE_BUTTON 18
#define POSITION_LOAD_BUTTON 15
#define POSITION_SAVE_BUTTON 13
#define POSITION_BPM_BUTTON 11
#define POSITION_STOP_BUTTON 10
#define POSITION_PLAY_BUTTON 8
#define POSITION_RECORD_BUTTON 7
#define POSITION_BAR_BUTTON 5
#define DOT_OFFSET_X 40  //STEP_FRAME_W * 2 + 8
#define DOT_OFFSET_Y 24  //STEP_FRAME_H + 8
#define DOT_RADIUS 5
#define OCTAVE_CHANGE_LEFTMOST 17
#define OCTAVE_CHANGE_RIGHTMOST 20
#define OCTAVE_CHANGE_UP_TOPMOST 1
#define OCTAVE_CHANGE_UP_BOTTOMMOST 4
#define OCTAVE_CHANGE_DOWN_TOPMOST 7
#define OCTAVE_CHANGE_DOWN_BOTTOMMOST 10
#define OCTAVE0 0
#define OCTAVE1 12
#define OCTAVE2 24
#define OCTAVE3 36
#define OCTAVE4 48
#define OCTAVE5 60
#define OCTAVE6 72
#define OCTAVE7 84
#define CHORD_QUANT 7
#define velocity 96
#define velocityOff 0
#define VALUE_NOTEOFF 0

#define NUM_CLIPS 8
#define NUM_INSTRUMENTS 8
#define NUM_VOICES 4
#define NUM_STEPS 16

//clip handling variables
//bool held_notes[inst][127]
byte desired_step;
byte desired_clip;
byte desired_instrument;
byte clip[NUM_INSTRUMENTS][NUM_CLIPS][NUM_STEPS] {
  { //channel1
    { 0,  0,  0,  0,   0,  0,  0,  0,   0,  0,  0,  0,   0,  0,  0,  0},
    { 0,  0,  0,  0,   0,  0,  0,  0,   0,  0,  0,  0,   0,  0,  0,  0},
    { 0,  0,  0,  0,   0,  0,  0,  0,   0,  0,  0,  0,   0,  0,  0,  0},
    { 0,  0,  0,  0,   0,  0,  0,  0,   0,  0,  0,  0,   0,  0,  0,  0},
    { 0,  0,  0,  0,   0,  0,  0,  0,   0,  0,  0,  0,   0,  0,  0,  0},
    { 0,  0,  0,  0,   0,  0,  0,  0,   0,  0,  0,  0,   0,  0,  0,  0},
    { 0,  0,  0,  0,   0,  0,  0,  0,   0,  0,  0,  0,   0,  0,  0,  0},
    { 0,  0,  0,  0,   0,  0,  0,  0,   0,  0,  0,  0,   0,  0,  0,  0}
  },
  { //channel2
    { 0,  0,  0,  0,   0,  0,  0,  0,   0,  0,  0,  0,   0,  0,  0,  0},
    { 0,  0,  0,  0,   0,  0,  0,  0,   0,  0,  0,  0,   0,  0,  0,  0},
    { 0,  0,  0,  0,   0,  0,  0,  0,   0,  0,  0,  0,   0,  0,  0,  0},
    { 0,  0,  0,  0,   0,  0,  0,  0,   0,  0,  0,  0,   0,  0,  0,  0},
    { 0,  0,  0,  0,   0,  0,  0,  0,   0,  0,  0,  0,   0,  0,  0,  0},
    { 0,  0,  0,  0,   0,  0,  0,  0,   0,  0,  0,  0,   0,  0,  0,  0},
    { 0,  0,  0,  0,   0,  0,  0,  0,   0,  0,  0,  0,   0,  0,  0,  0},
    { 0,  0,  0,  0,   0,  0,  0,  0,   0,  0,  0,  0,   0,  0,  0,  0}
  },
  { //channel3
    { 0,  0,  0,  0,   0,  0,  0,  0,   0,  0,  0,  0,   0,  0,  0,  0},
    { 0,  0,  0,  0,   0,  0,  0,  0,   0,  0,  0,  0,   0,  0,  0,  0},
    { 0,  0,  0,  0,   0,  0,  0,  0,   0,  0,  0,  0,   0,  0,  0,  0},
    { 0,  0,  0,  0,   0,  0,  0,  0,   0,  0,  0,  0,   0,  0,  0,  0},
    { 0,  0,  0,  0,   0,  0,  0,  0,   0,  0,  0,  0,   0,  0,  0,  0},
    { 0,  0,  0,  0,   0,  0,  0,  0,   0,  0,  0,  0,   0,  0,  0,  0},
    { 0,  0,  0,  0,   0,  0,  0,  0,   0,  0,  0,  0,   0,  0,  0,  0},
    { 0,  0,  0,  0,   0,  0,  0,  0,   0,  0,  0,  0,   0,  0,  0,  0}
  },
  { //channel4
    { 0,  0,  0,  0,   0,  0,  0,  0,   0,  0,  0,  0,   0,  0,  0,  0},
    { 0,  0,  0,  0,   0,  0,  0,  0,   0,  0,  0,  0,   0,  0,  0,  0},
    { 0,  0,  0,  0,   0,  0,  0,  0,   0,  0,  0,  0,   0,  0,  0,  0},
    { 0,  0,  0,  0,   0,  0,  0,  0,   0,  0,  0,  0,   0,  0,  0,  0},
    { 0,  0,  0,  0,   0,  0,  0,  0,   0,  0,  0,  0,   0,  0,  0,  0},
    { 0,  0,  0,  0,   0,  0,  0,  0,   0,  0,  0,  0,   0,  0,  0,  0},
    { 0,  0,  0,  0,   0,  0,  0,  0,   0,  0,  0,  0,   0,  0,  0,  0},
    { 0,  0,  0,  0,   0,  0,  0,  0,   0,  0,  0,  0,   0,  0,  0,  0}
  },
  { //channel5
    { 0,  0,  0,  0,   0,  0,  0,  0,   0,  0,  0,  0,   0,  0,  0,  0},
    { 0,  0,  0,  0,   0,  0,  0,  0,   0,  0,  0,  0,   0,  0,  0,  0},
    { 0,  0,  0,  0,   0,  0,  0,  0,   0,  0,  0,  0,   0,  0,  0,  0},
    { 0,  0,  0,  0,   0,  0,  0,  0,   0,  0,  0,  0,   0,  0,  0,  0},
    { 0,  0,  0,  0,   0,  0,  0,  0,   0,  0,  0,  0,   0,  0,  0,  0},
    { 0,  0,  0,  0,   0,  0,  0,  0,   0,  0,  0,  0,   0,  0,  0,  0},
    { 0,  0,  0,  0,   0,  0,  0,  0,   0,  0,  0,  0,   0,  0,  0,  0},
    { 0,  0,  0,  0,   0,  0,  0,  0,   0,  0,  0,  0,   0,  0,  0,  0}
  },
  { //channel6
    { 0,  0,  0,  0,   0,  0,  0,  0,   0,  0,  0,  0,   0,  0,  0,  0},
    { 0,  0,  0,  0,   0,  0,  0,  0,   0,  0,  0,  0,   0,  0,  0,  0},
    { 0,  0,  0,  0,   0,  0,  0,  0,   0,  0,  0,  0,   0,  0,  0,  0},
    { 0,  0,  0,  0,   0,  0,  0,  0,   0,  0,  0,  0,   0,  0,  0,  0},
    { 0,  0,  0,  0,   0,  0,  0,  0,   0,  0,  0,  0,   0,  0,  0,  0},
    { 0,  0,  0,  0,   0,  0,  0,  0,   0,  0,  0,  0,   0,  0,  0,  0},
    { 0,  0,  0,  0,   0,  0,  0,  0,   0,  0,  0,  0,   0,  0,  0,  0},
    { 0,  0,  0,  0,   0,  0,  0,  0,   0,  0,  0,  0,   0,  0,  0,  0}
  },
  { //channel7
    { 0,  0,  0,  0,   0,  0,  0,  0,   0,  0,  0,  0,   0,  0,  0,  0},
    { 0,  0,  0,  0,   0,  0,  0,  0,   0,  0,  0,  0,   0,  0,  0,  0},
    { 0,  0,  0,  0,   0,  0,  0,  0,   0,  0,  0,  0,   0,  0,  0,  0},
    { 0,  0,  0,  0,   0,  0,  0,  0,   0,  0,  0,  0,   0,  0,  0,  0},
    { 0,  0,  0,  0,   0,  0,  0,  0,   0,  0,  0,  0,   0,  0,  0,  0},
    { 0,  0,  0,  0,   0,  0,  0,  0,   0,  0,  0,  0,   0,  0,  0,  0},
    { 0,  0,  0,  0,   0,  0,  0,  0,   0,  0,  0,  0,   0,  0,  0,  0},
    { 0,  0,  0,  0,   0,  0,  0,  0,   0,  0,  0,  0,   0,  0,  0,  0}
  },
  { //channel8
    {36,  0,  0,  0,  36,  0,  0,  0,  37,  0,  0,  0,  39,  0,  0,  0},
    { 0,  0,  0,  0,   0,  0,  0,  0,   0,  0,  0,  0,   0,  0,  0,  0},
    { 0,  0,  0,  0,   0,  0,  0,  0,   0,  0,  0,  0,   0,  0,  0,  0},
    { 0,  0,  0,  0,   0,  0,  0,  0,   0,  0,  0,  0,   0,  0,  0,  0},
    { 0,  0,  0,  0,   0,  0,  0,  0,   0,  0,  0,  0,   0,  0,  0,  0},
    { 0,  0,  0,  0,   0,  0,  0,  0,   0,  0,  0,  0,   0,  0,  0,  0},
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

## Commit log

2022-08-27 8-channel polymadness
    first step is one note above.
    So the kick C3 has its first step-entry one notevalue plus C#3, for every note...
    Only the first step has this issue!!
    [ch1Sequencer.ino, drumsequencer1.ino, midiClockHandling.ino]
2022-09-02 added some bugs ;P
    [15stepImplement.ino, 15stepTeensyDAW1.ino]
2022-09-05 added channel selection per track
2022-09-25 added tutorial and plugins
    [PCB_teensyDAW_2022-09-21-2.dwg, PCB_teensyDAW_2022-09-21-2.dxf, PCB_teensyDAW_2022-09-21.dxf]
2022-10-25 3.5 more or less final
    [teensydaw41.ods]
2022-11-02 big improvment in clock stability
    [ch1Sequencer.ino, ch8Sequencer.ino, songMode.ino]
2022-11-26 teensy 4.1 port
    [PCB_teensyDAW_2022-09-21-2.dwg, PCB_teensyDAW_2022-09-21-2.dxf, PCB_teensyDAW_2022-09-21.dxf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]
2022-11-28 2 raw samplers instead of a wav sampler
2022-12-30 hardware updated
    [buttonextension12.stl, touchdaw41Enc.stl, touchdaw41obenEnc.stl]
2022-12-31 bom added
    [BOM_teensyDAW4 enc_2022-12-31.csv]
2022-12-31 revised bottom housing
    [touchdaw41Enc.stl]
2023-01-03 Update Teensy TouchDAW user Manual.pdf
2023-01-11 LP device control
2023-01-22 LP and other bugs
    [a_launchpad.ino, b_functions.ino, d_midi.ino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]
2023-02-21 clock divisions cause a crash
    [b_functions.ino, c_variables.h, d_midi.ino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]
2023-02-21 Revert "Add files via upload"
    This reverts commit eda59c237df41c1e55419d723e02467dcf84828a.
    [b_functions.ino, d_midi.ino, g_ch1Sequencer.ino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]
2023-02-22 this, i´m lucky again
    [BOM_teensyDAW4 enc_2022-12-31.csv, PCB_teensyDAW_2022-09-21-2.dwg, PCB_teensyDAW_2022-09-21-2.dxf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]
2023-03-11 Plugin: dTune + bugfixes
    [TeensyTouchDAW.ino, b_functions.ino, l_Pl1Chord.ino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]
